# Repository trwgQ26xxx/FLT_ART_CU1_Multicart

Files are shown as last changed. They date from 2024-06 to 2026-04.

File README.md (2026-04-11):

# Multicart ROM module for Fiat Lancia Tester \ Alfa Romeo Tester \ Check Up 1

A multicart ROM module that replaces eight standard FLT modules. It contains eight ROM sets stored in a 512kB (4Mbit) flash memory, which can be switched on the fly.

Two variants are implemented: one using an Atmel AT89C2051 MCU (revisions A - green and B - blue), and another based on a Microchip ATtiny806 (revision C - yellow).

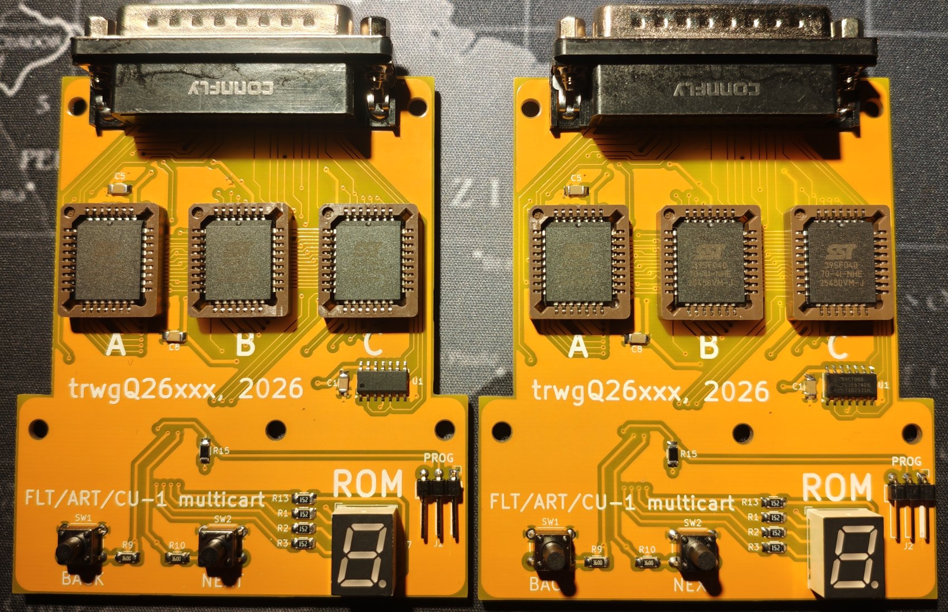
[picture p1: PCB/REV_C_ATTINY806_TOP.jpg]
REV_C_ATTINY806_TOP

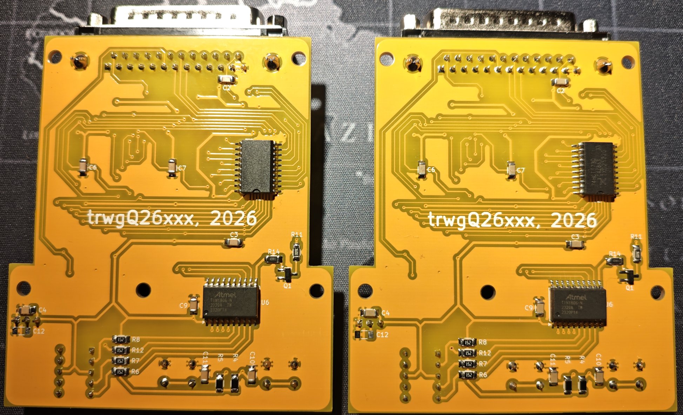
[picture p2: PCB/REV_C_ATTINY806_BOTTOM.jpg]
REV_C_ATTINY806_BOTTOM


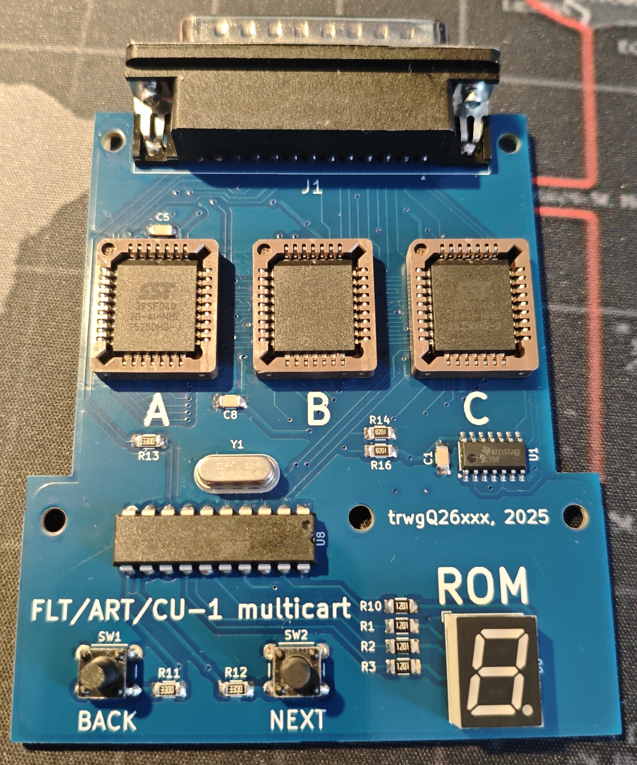
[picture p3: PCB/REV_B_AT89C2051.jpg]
REV_B_AT89C2051


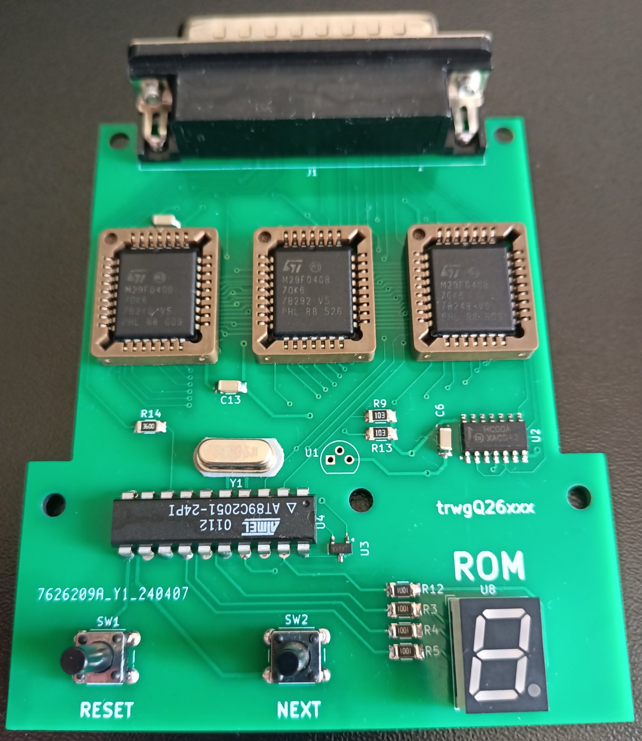
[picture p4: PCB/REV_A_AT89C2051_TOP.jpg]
REV_A_AT89C2051_TOP

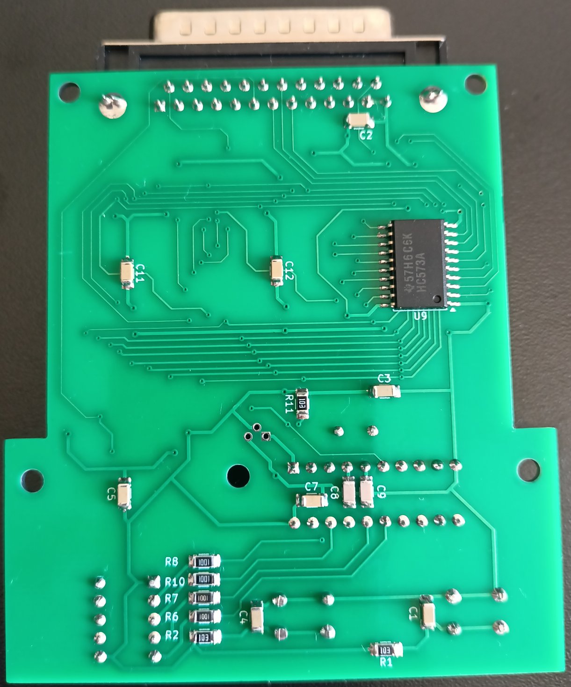
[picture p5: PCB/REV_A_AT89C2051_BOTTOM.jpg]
REV_A_AT89C2051_BOTTOM


# Disclaimer

I do not consent to the use of all or part of the project for commercial purposes!

Nie wyrażam zgody na wykorzystanie całości bądź części projektu w celach zarobkowych!

# License

Shield: [][cc-by-nc-sa]

This work is licensed under a
[Creative Commons Attribution-NonCommercial-ShareAlike 4.0 International License][cc-by-nc-sa].

[][cc-by-nc-sa]

[cc-by-nc-sa]: http://creativecommons.org/licenses/by-nc-sa/4.0/
[cc-by-nc-sa-image]: https://licensebuttons.net/l/by-nc-sa/4.0/88x31.png
[cc-by-nc-sa-shield]: https://img.shields.io/badge/License-CC%20BY--NC--SA%204.0-lightgrey.svg

# Directories organization

- **firmware** - MCU firmware written in C, provided for both the AT89C2051 and ATtiny806 variants.
- **merge** - A script that automatically combines up to eight modules into a single package suitable for loading onto the multicart.
- **PCB** - KiCad PCB project files, available for both the AT89C2051 and ATtiny806 hardware revisions.
- **DS** - Datasheets for all components used in the project.

# Instructions

Switching modules (ROMs) is accomplished by pressing the BACK and NEXT keys. With each press, a dot lights up on the display for the FLT reset time (approximately 200 ms). The display indicates the number of the currently running module.

The FLASH memories used, of 39SF040 type (or equivalent), have a capacity of 512kB. Considering that the largest FLT modules ROMs are 64kB, I designed the multicart's capacity to accomodate 8 modules.

# ROMS preparation

The FLASH memory contents can be changed according to the following principles.

**ROM index** | **Base offset**
:---: | :---:
1 | 0x00000
2 | 0x10000
3 | 0x20000
4 | 0x30000
5 | 0x40000
6 | 0x50000
7 | 0x60000
8 | 0x70000

Let's assume we want to load the module at index 3, for which the base offset is 0x20000.

**ROM** | **SIZE** | **The ROM given is PRESENT in the module being loaded at index 3** | **The ROM given is NOT PRESENT in the module being loaded at index 3**
:---: | :---: | :---: | :---:
A | 8kB | Load the content of ROM A into FLASH memory A addresses 0x20000-0x21FFF.Fill addresses 0x22000-0x2FFFF of FLASH memory A with 0xFF. | Fill addresses 0x20000-0x2FFFF of FLASH memory A with 0xFF.
B | 32kB | Load the content of ROM B into FLASH memory B addresses 0x28000-0x2FFFF. Fill addresses 0x20000-0x27FFF of FLASH memory B with 0xFF. | ROM B is always present.
B | 64kB | Load the content of ROM B into FLASH memory B addresses 0x20000-0x2FFFF. | ROM B is always present.
C | 32kB | Load the content of ROM C into FLASH memory C addresses 0x28000-0x2FFFF. Fill addresses 0x20000-0x27FFF of FLASH memory C with 0xFF. | Fill addresses 0x20000-0x2FFFF of FLASH memory C with 0xFF.
C | 64kB | Load the content of ROM C into FLASH memory C addresses 0x20000-0x2FFFF. | Fill addresses 0x20000-0x2FFFF of FLASH memory C with 0xFF.

It should be noted here that the utilization of FLASH memory A is at most 12.5%, as only 8kB of each 64kB bank is utilized. However, I opted for this solution to simplify the process of preparing Flash memory content, given the use of identical offsets.

# Notes

- Use the APX810-40SA as the reset supervisor for the AT89C2051 MCU (U7 on the PCB) in revisions A and B.

- Wiring the MPLAB ICD5 8P8C Connector to the Multicart PROG Connector (Revision C):

**SIGNAL** | **PROG pin** | **8P8C pin**
:---: | :---: | :---:
GND | 1 | 5
UPDI | 2 | 4
VCC | 3 | 6

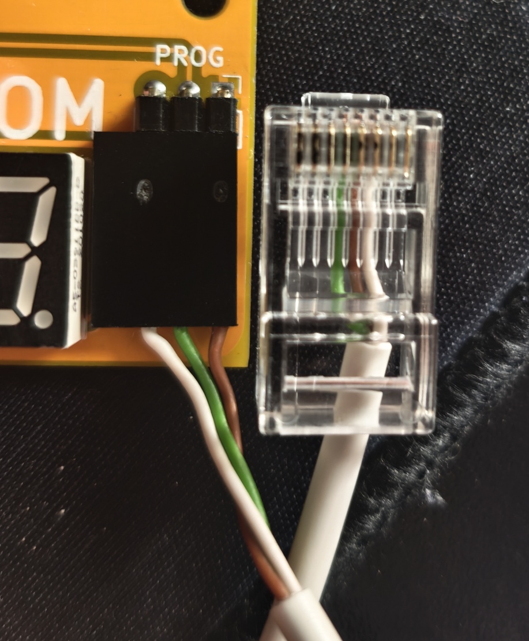
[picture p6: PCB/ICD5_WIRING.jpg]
ICD5_WIRING


- 0.28" LED displays are available in two pinout variants. The first variant uses common pins 1 and 6. The second variant uses common pins 3 and 8. **Revisions B and C of the project require the display with common pins 3 and 8.** The version with common pins 1 and 6 was used only in revision A.

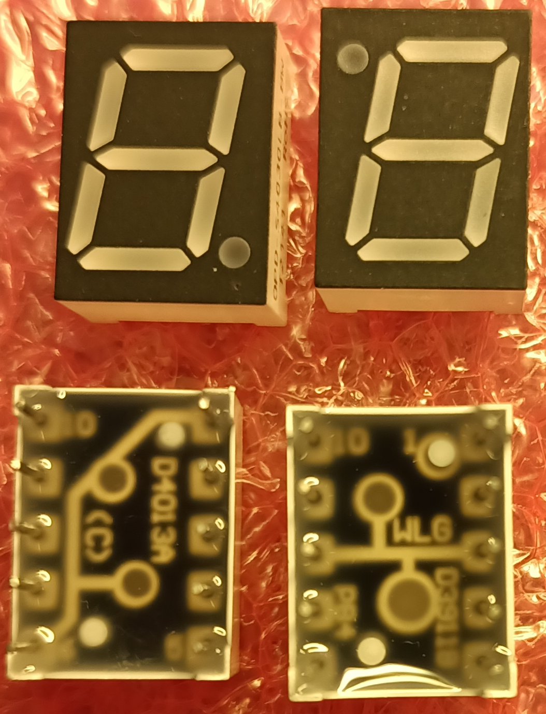
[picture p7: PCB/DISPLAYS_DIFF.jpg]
DISPLAYS_DIFF


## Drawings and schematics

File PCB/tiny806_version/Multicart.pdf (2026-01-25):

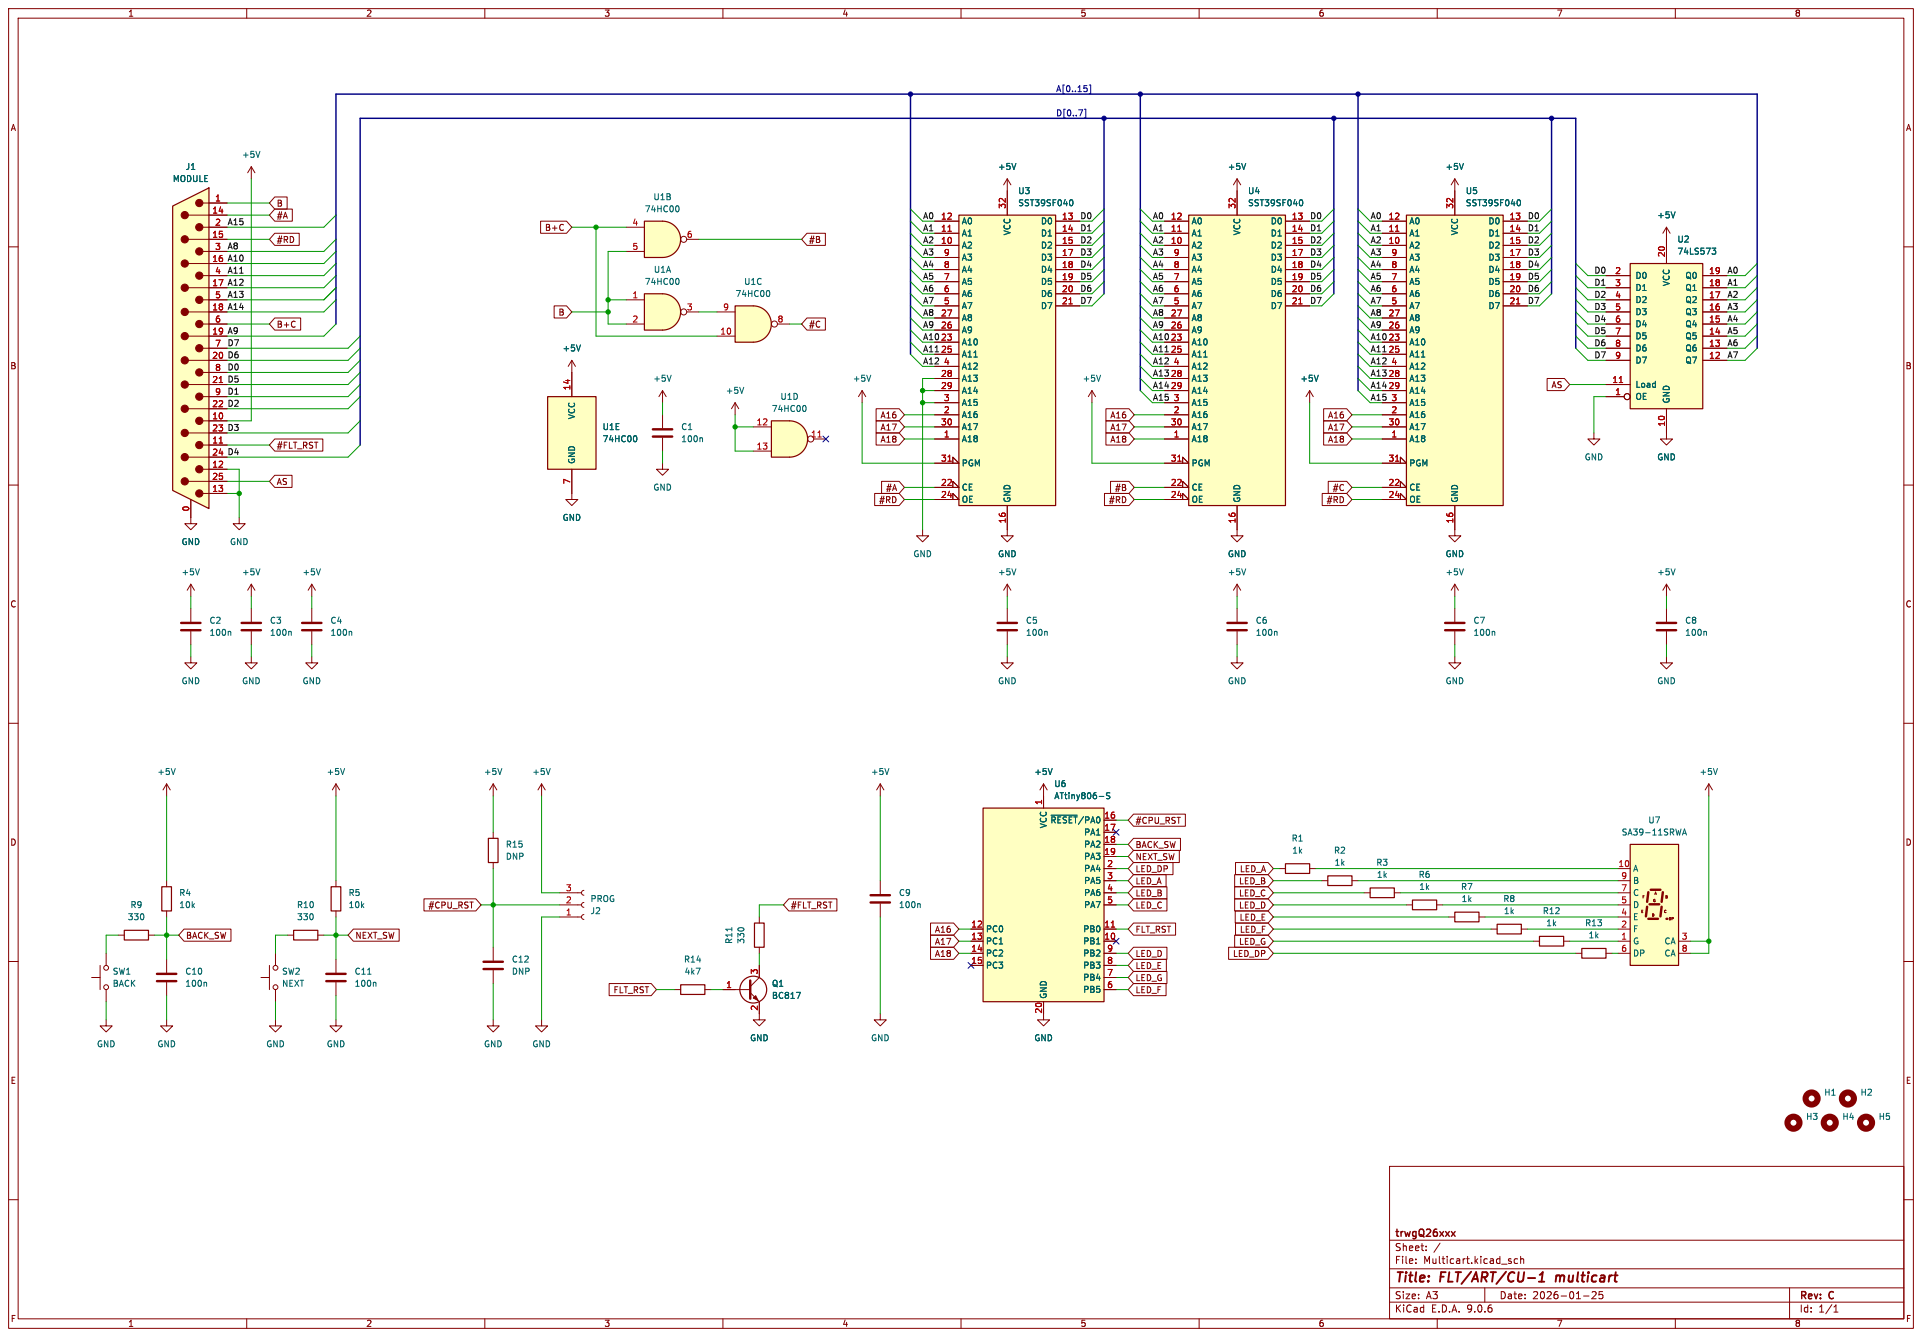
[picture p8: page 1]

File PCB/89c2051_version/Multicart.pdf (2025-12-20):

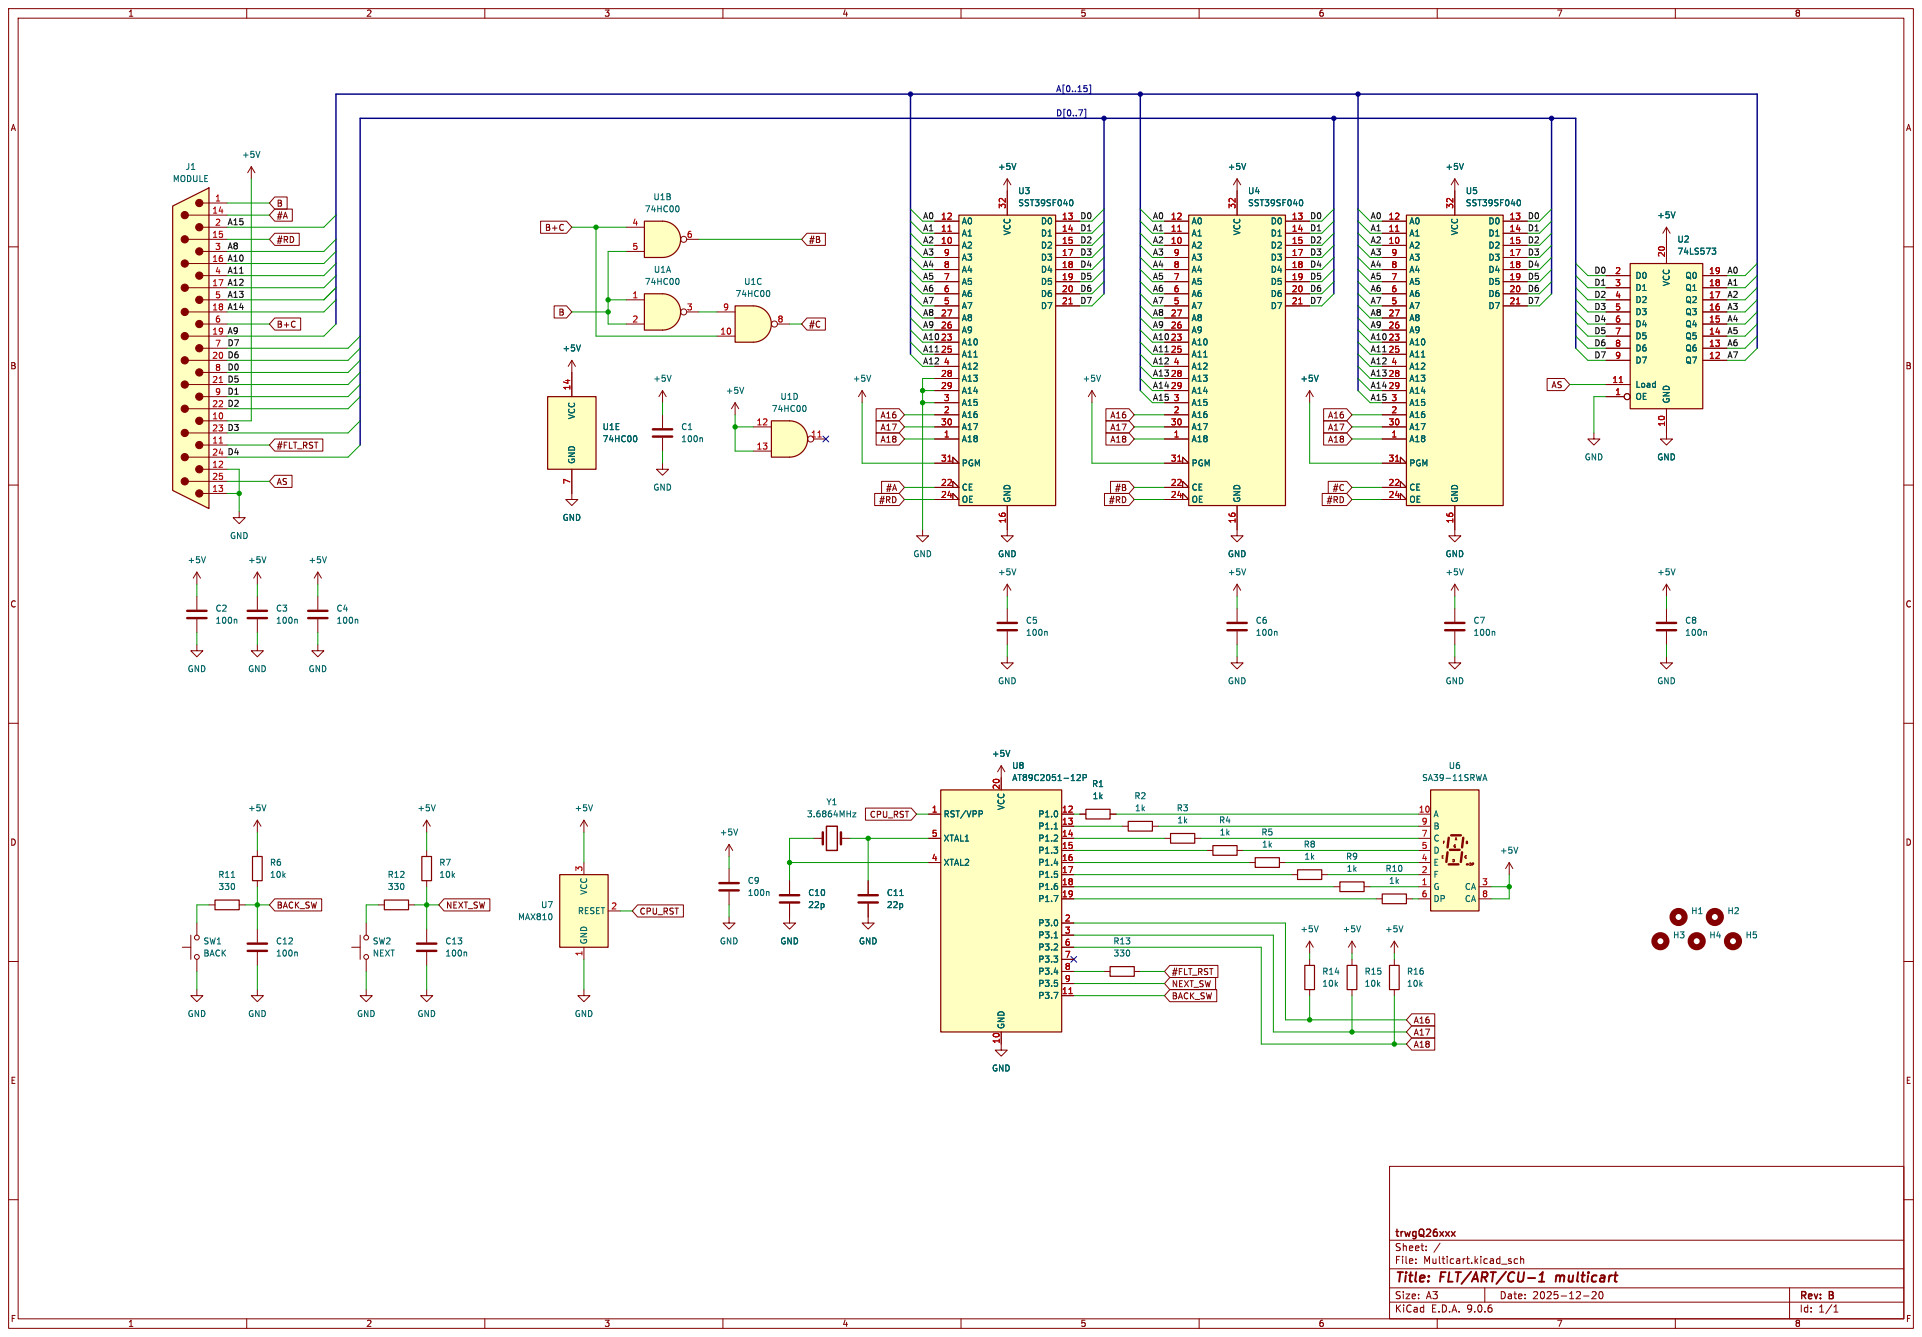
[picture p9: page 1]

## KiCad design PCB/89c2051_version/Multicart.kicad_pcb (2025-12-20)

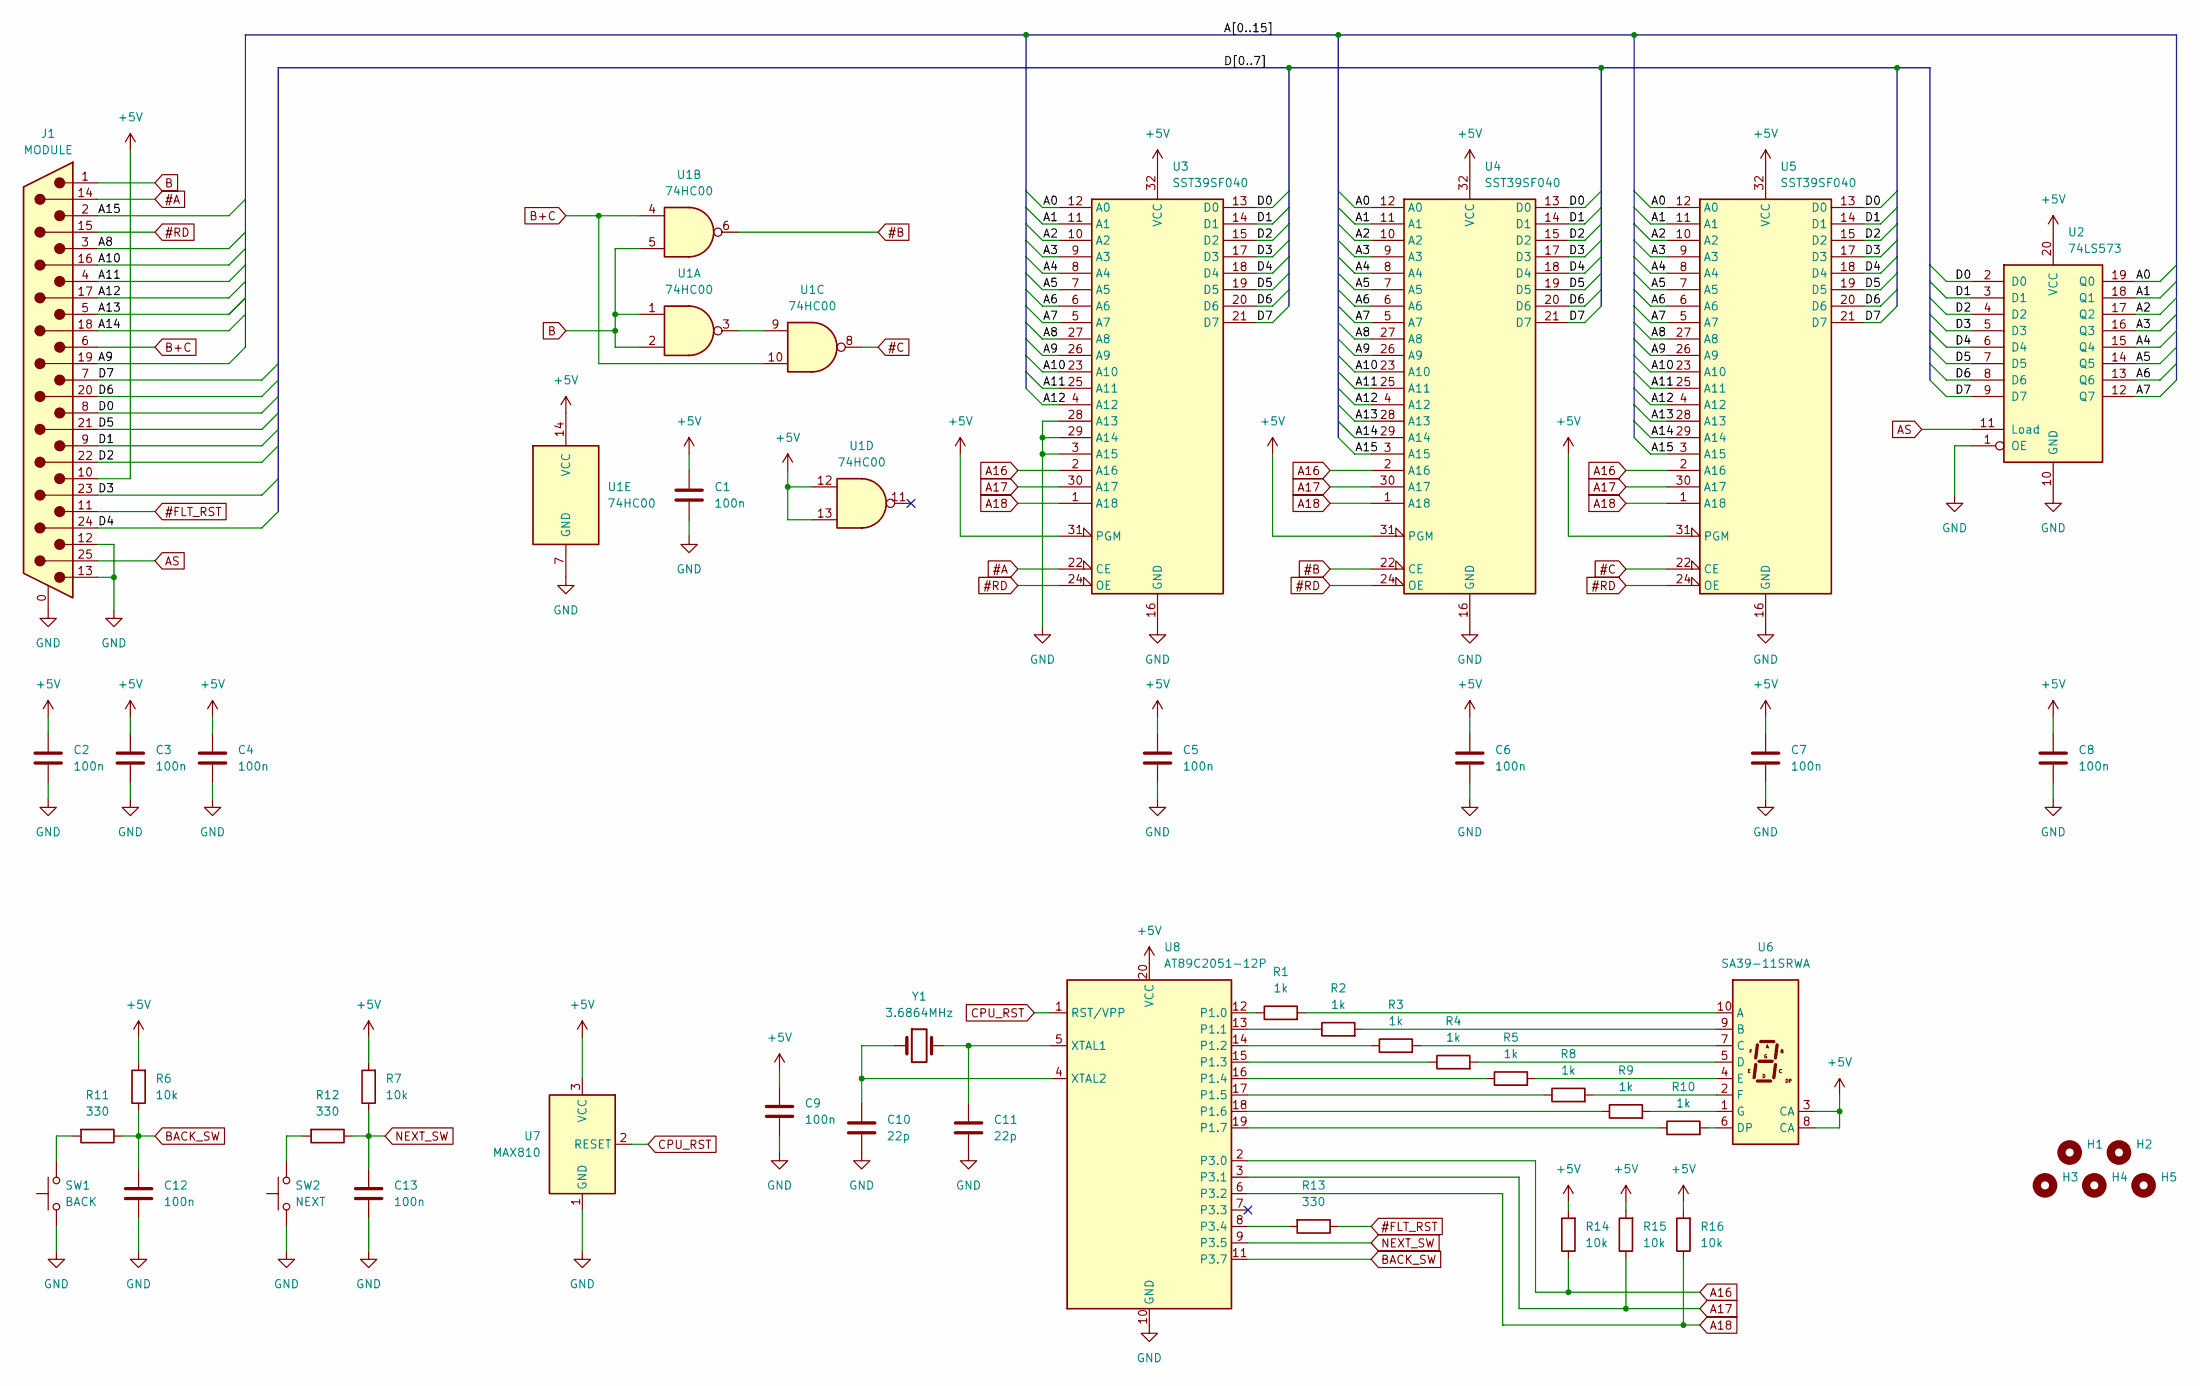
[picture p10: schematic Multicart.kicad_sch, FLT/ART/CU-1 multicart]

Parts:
C1, C2, C3, C4, C5, C6, C7, C8, C9, C12, C13: 100n; C_1206_3216Metric_Pad1.33x1.80mm_HandSolder
C10, C11: 22p; C_1206_3216Metric_Pad1.33x1.80mm_HandSolder
H1, H2, H3, H4, H5: MountingHole_3.2mm_M3_DIN965
J1: MODULE; DSUB-25_Male_Horizontal_P2.77x2.84mm_EdgePinOffset4.94mm_Ho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
R1, R2, R3, R4, R5, R8, R9, R10: 1k; R_1206_3216Metric_Pad1.30x1.75mm_HandSolder
R6, R7, R14, R15, R16: 10k; R_1206_3216Metric_Pad1.30x1.75mm_HandSolder
R11, R12, R13: 330; R_1206_3216Metric_Pad1.30x1.75mm_HandSolder
SW1: BACK; SW_PUSH_6mm
SW2: NEXT; SW_PUSH_6mm
U1: 74HC00; SOIC-14_3.9x8.7mm_P1.27mm
U2: 74LS573; SOIC-20W_7.5x12.8mm_P1.27mm
U3, U4, U5: SST39SF040; PLCC-32_11.4x14.0mm_P1.27mm
U6: SA39-11SRWA; Sx39-1xxxxx
U7: MAX810; SOT-23
U8: AT89C2051-12P; DIP-20_W7.62mm
Y1: 3.6864MHz; Crystal_HC49-4H_Vertical

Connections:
#A: J1.14, U3.22 (CE)
#B: U1.6, U4.22 (CE)
#C: U1.8, U5.22 (CE)
#FLT_RST: J1.11, R13.1
#RD: J1.15, U3.24 (OE), U4.24 (OE), U5.24 (OE)
+5V: C1.1, C2.1, C3.1, C4.1, C5.1, C6.1, C7.1, C8.1, C9.1, J1.10, R6.2, R7.2, R14.2, R15.2, R16.2, U1.12, U1.13, U1.14 (VCC), U2.20 (VCC), U3.31 (PGM), U3.32 (VCC), U4.31 (PGM), U4.32 (VCC), U5.31 (PGM), U5.32 (VCC), U6.3 (CA), U6.8 (CA), U7.3 (VCC), U8.20 (VCC)
/A0: U2.19 (Q0), U3.12 (A0), U4.12 (A0), U5.12 (A0)
/A1: U2.18 (Q1), U3.11 (A1), U4.11 (A1), U5.11 (A1)
/A2: U2.17 (Q2), U3.10 (A2), U4.10 (A2), U5.10 (A2)
/A3: U2.16 (Q3), U3.9 (A3), U4.9 (A3), U5.9 (A3)
/A4: U2.15 (Q4), U3.8 (A4), U4.8 (A4), U5.8 (A4)
/A5: U2.14 (Q5), U3.7 (A5), U4.7 (A5), U5.7 (A5)
/A6: U2.13 (Q6), U3.6 (A6), U4.6 (A6), U5.6 (A6)
/A7: U2.12 (Q7), U3.5 (A7), U4.5 (A7), U5.5 (A7)
/A8: J1.3, U3.27 (A8), U4.27 (A8), U5.27 (A8)
/A9: J1.19, U3.26 (A9), U4.26 (A9), U5.26 (A9)
/A10: J1.16, U3.23 (A10), U4.23 (A10), U5.23 (A10)
/A11: J1.4, U3.25 (A11), U4.25 (A11), U5.25 (A11)
/A12: J1.17, U3.4 (A12), U4.4 (A12), U5.4 (A12)
/A13: J1.5, U4.28 (A13), U5.28 (A13)
/A14: J1.18, U4.29 (A14), U5.29 (A14)
/A15: J1.2, U4.3 (A15), U5.3 (A15)
/D0: J1.8, U2.2 (D0), U3.13 (D0), U4.13 (D0), U5.13 (D0)
/D1: J1.9, U2.3 (D1), U3.14 (D1), U4.14 (D1), U5.14 (D1)
/D2: J1.22, U2.4 (D2), U3.15 (D2), U4.15 (D2), U5.15 (D2)
/D3: J1.23, U2.5 (D3), U3.17 (D3), U4.17 (D3), U5.17 (D3)
/D4: J1.24, U2.6 (D4), U3.18 (D4), U4.18 (D4), U5.18 (D4)
/D5: J1.21, U2.7 (D5), U3.19 (D5), U4.19 (D5), U5.19 (D5)
/D6: J1.20, U2.8 (D6), U3.20 (D6), U4.20 (D6), U5.20 (D6)
/D7: J1.7, U2.9 (D7), U3.21 (D7), U4.21 (D7), U5.21 (D7)
A16: R14.1, U3.2 (A16), U4.2 (A16), U5.2 (A16), U8.2 (P3.0)
A17: R15.1, U3.30 (A17), U4.30 (A17), U5.30 (A17), U8.3 (P3.1)
A18: R16.1, U3.1 (A18), U4.1 (A18), U5.1 (A18), U8.6 (P3.2)
AS: J1.25, U2.11 (Load)
B: J1.1, U1.1, U1.2, U1.5
B+C: J1.6, U1.4, U1.10
BACK_SW: C12.1, R6.1, R11.1, U8.11 (P3.7)
CPU_RST: U7.2 (RESET), U8.1 (RST/VPP)
GND: C1.2, C2.2, C3.2, C4.2, C5.2, C6.2, C7.2, C8.2, C9.2, C10.2, C11.2, C12.2, C13.2, J1.0, J1.12, J1.13, SW1.1, SW2.1, U1.7 (GND), U2.1 (OE), U2.10 (GND), U3.3 (A15), U3.16 (GND), U3.28 (A13), U3.29 (A14), U4.16 (GND), U5.16 (GND), U7.1 (GND), U8.10 (GND)
NEXT_SW: C13.1, R7.1, R12.1, U8.9 (P3.5)
unnamed: R11.2, SW1.2
unnamed: R12.2, SW2.2
unnamed: U1.3, U1.9
unnamed: R1.2, U6.10 (A)
unnamed: R2.2, U6.9 (B)
unnamed: R3.2, U6.7 (C)
unnamed: R4.2, U6.5 (D)
unnamed: R10.2, U6.6 (DP)
unnamed: R5.2, U6.4 (E)
unnamed: R8.2, U6.2 (F)
unnamed: R9.2, U6.1 (G)
unnamed: R1.1, U8.12 (P1.0)
unnamed: R2.1, U8.13 (P1.1)
unnamed: R3.1, U8.14 (P1.2)
unnamed: R4.1, U8.15 (P1.3)
unnamed: R5.1, U8.16 (P1.4)
unnamed: R8.1, U8.17 (P1.5)
unnamed: R9.1, U8.18 (P1.6)
unnamed: R10.1, U8.19 (P1.7)
unnamed: R13.2, U8.8 (P3.4)
unnamed: C11.1, U8.5 (XTAL1), Y1.2
unnamed: C10.1, U8.4 (XTAL2), Y1.1

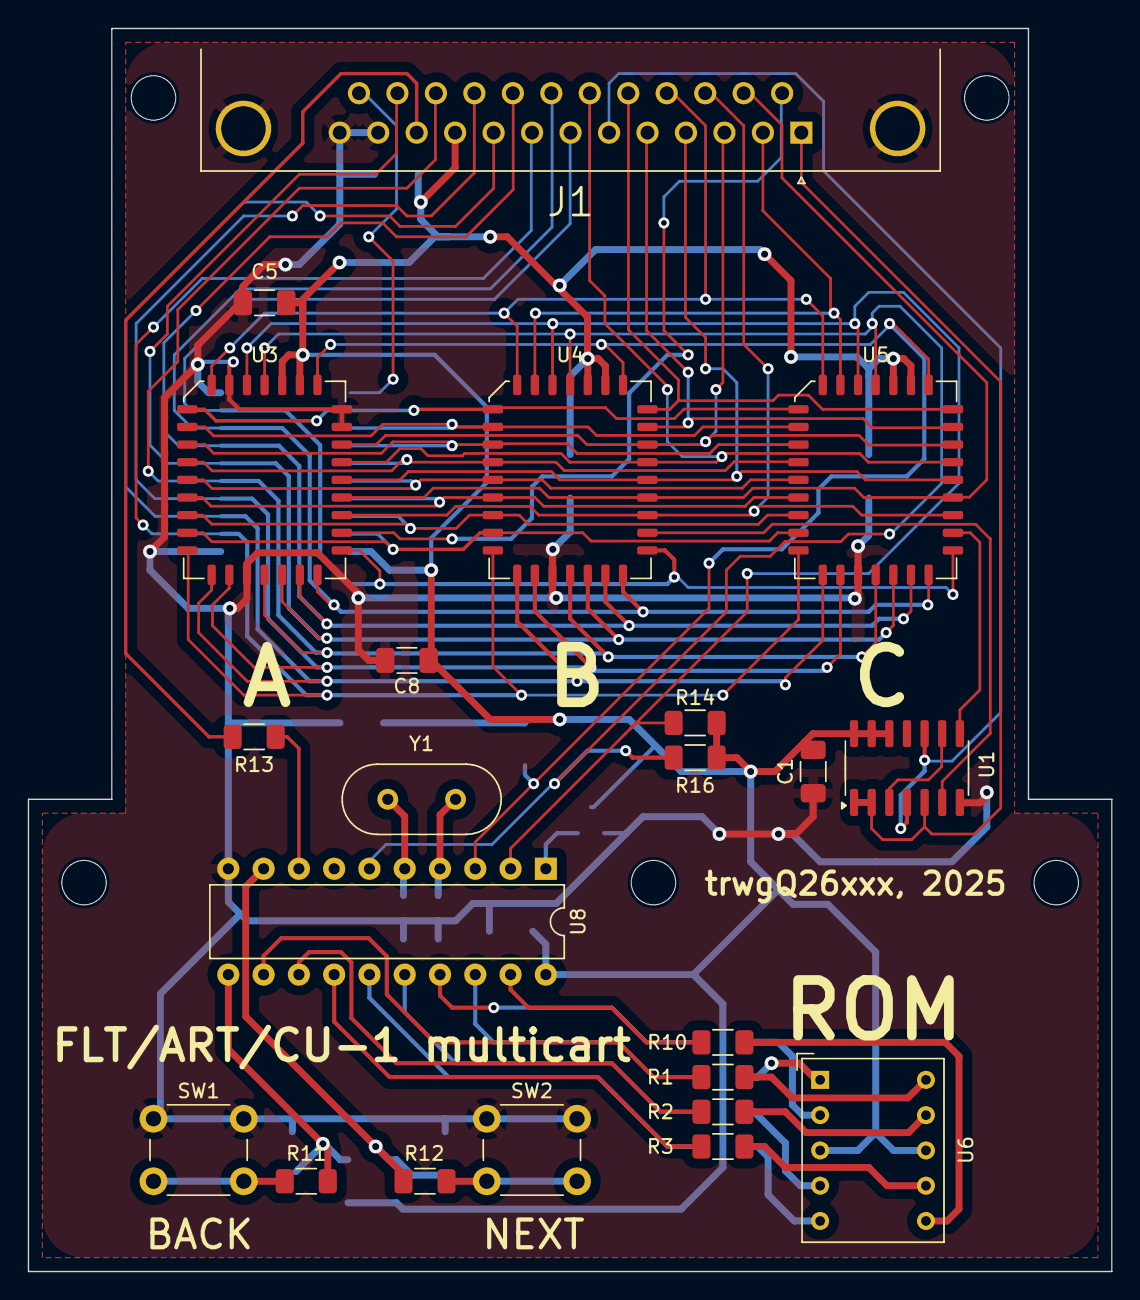
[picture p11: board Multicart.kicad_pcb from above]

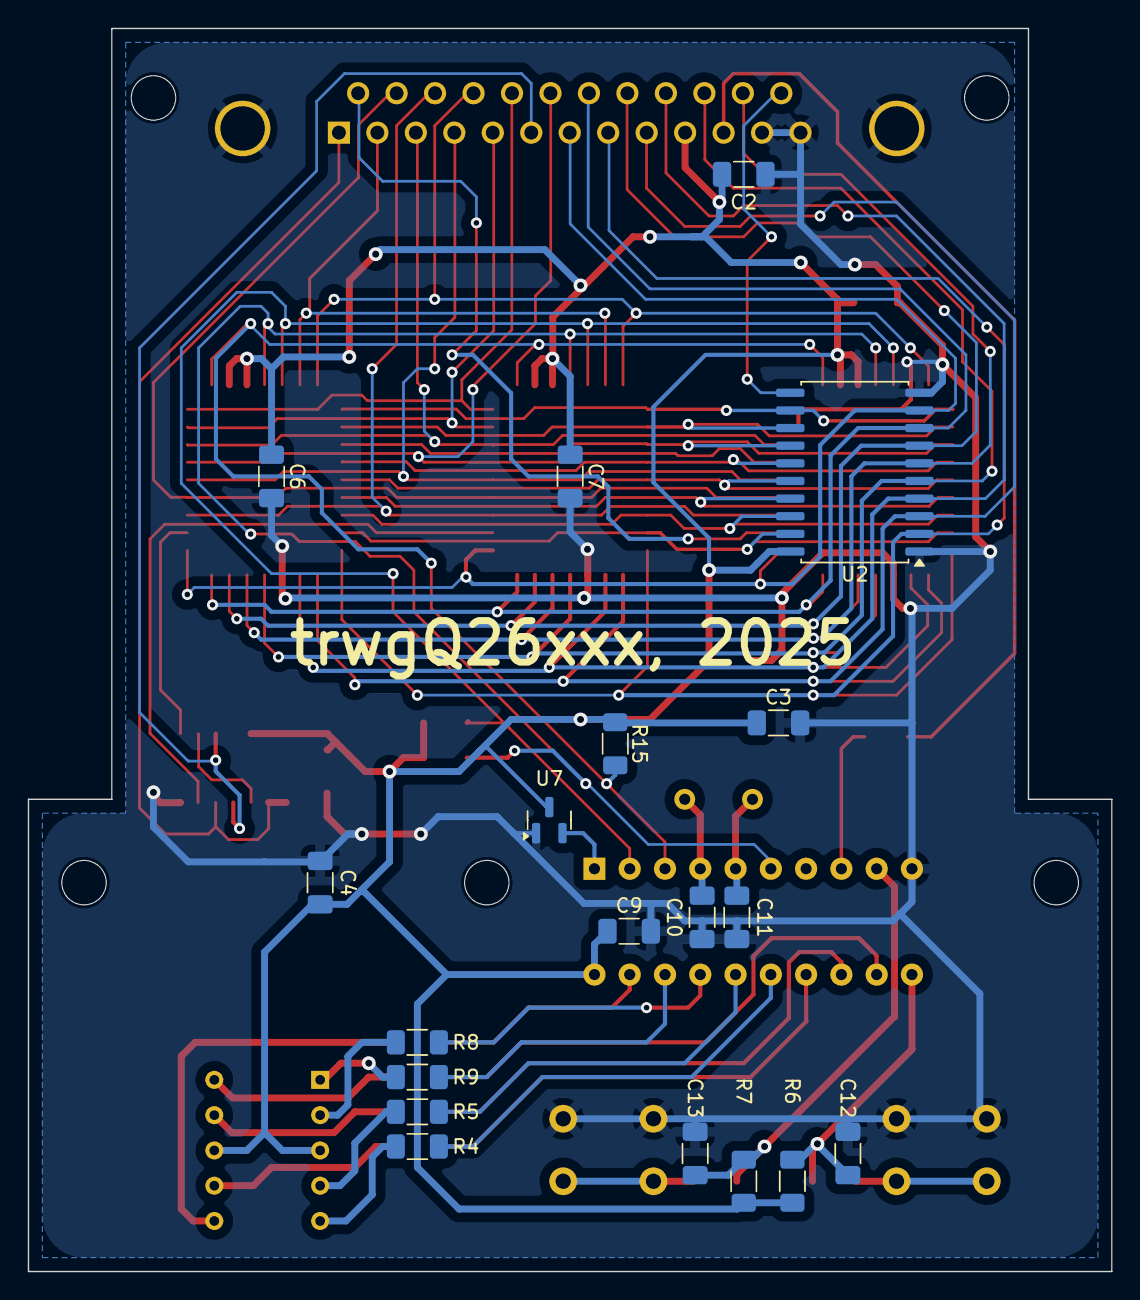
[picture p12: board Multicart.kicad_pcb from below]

Board: 2 copper layers, 78.0 x 89.5 mm, 46 parts (19 on the bottom side), 62 nets.

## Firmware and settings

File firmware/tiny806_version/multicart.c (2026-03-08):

/*
Project name:	FLT/CU1 multicart
Author: 		trwgQ26xxx
Date:			25.02.2026
Target MCUs:	Attiny 406/806
Compiler:		AVR_8_bit_GNU_Toolchain_4.0.0_52), Microchip.ATtiny_DFP.3.3.272
*/

#include <stdint.h>
#include <stdbool.h>

#include <avr/io.h>
#include <avr/interrupt.h>
#include <avr/wdt.h>
#include <avr/fuse.h>

/*
------------------ CONNECTIONS ------------------

7 segment display:
PA5 - PA7 => A, B, C; PB2 - PB5 => D, E, G, F; PA4 = DP

Flash memory address lines:
PC0 - PC2 => A16 - A18; PC3 = NC (A19 - FFU)

FLT reset:
PB0 = #FLT_RST

Push buttons:
PA3 = NEXT_SW, PA2 = BACK_SW

------------------ CONNECTIONS ------------------
*/

#define NUMBER_OF_BANKS	8

#define F_TIMER			(F_CPU / 256)					/* Hz, for TCA0 with DIV256 prescaler */
#define KEYB_DELAY		200								/* ms */
#define TIMER_VAL		((KEYB_DELAY * F_TIMER) / 1000)	/* ticks */
#define TIMER_VAL_MAX	0xFFFF							/* Max value for 16-bit timer */

#if (TIMER_VAL > TIMER_VAL_MAX)
	#error "Set keyboard delay is larger than maximum possible"
#endif

#define NEXT_KEY_IS_PRESSED				(!(PORTA.IN & (1 << 3)))
#define BACK_KEY_IS_PRESSED				(!(PORTA.IN & (1 << 2)))
#define ALL_KEYS_ARE_RELEASED			((PORTA.IN & (1 << 3)) && (PORTA.IN & (1 << 2)))

/* DIGITS: 1 - 8 */
volatile const unsigned char led_codes[NUMBER_OF_BANKS] = {0x06, 0x3B, 0x2F, 0x66, 0x6D, 0x7D, 0x07, 0x7F};

volatile bool keyboard_locked = false;
volatile uint8_t current_mem_bank = 0;

static void Run_FLT(bool run);
static void Change_mem_bank(uint8_t bank);
static void Update_LED_Display(uint8_t digit, bool dot_status);

static void Start_Timer(void);
static void Switch_Bank(void);

int main(void)
{
	/* Poke WDT */
	wdt_reset();

	/* FUSE set to 16MHz, enable 16 prescaler so F_CPU is 1MHz */
	_PROTECTED_WRITE(CLKCTRL.MCLKCTRLB, CLKCTRL_PDIV_16X_gc | CLKCTRL_PEN_bm);

	/* Initialize timer */
	TCA0.SINGLE.CTRLA = TCA_SINGLE_CLKSEL_DIV256_gc;	/* Set prescaler to 256 */
	TCA0.SINGLE.CTRLB = TCA_SINGLE_WGMODE_NORMAL_gc;	/* Set normal mode */
	TCA0.SINGLE.CTRLC = 0;								/* No compare channels */
	TCA0.SINGLE.CTRLD = 0;								/* No split mode */
	TCA0.SINGLE.CTRLECLR = TCA_SINGLE_DIR_bm;			/* Clear direction bit (count up mode) */
	TCA0.SINGLE.EVCTRL = 0;								/* No event control */
	TCA0.SINGLE.PER = TIMER_VAL;						/* Set period for desired delay */
	TCA0.SINGLE.CNT = 0;								/* Clear counter */

	TCA0.SINGLE.INTFLAGS = TCA_SINGLE_OVF_bm;			/* Clear interrupt flag */
	TCA0.SINGLE.INTCTRL = TCA_SINGLE_OVF_bm;			/* Enable overflow interrupt */

	/* Initialize memory bank switch output */
	PORTC.DIRSET = 0x0F;
	PORTC.OUTCLR = 0x0F;								/* Set to first bank */

	/* Initialize FLT reset output */
	PORTB.DIRSET = (1 << 0);
	PORTB.OUTSET = (1 << 0);							/* Hold in reset */

	/* Initialize display */
	PORTA.DIRSET = 0xF0; PORTB.DIRSET = 0x3C;
	PORTA.OUTSET = 0xF0; PORTB.OUTSET = 0x3C;			/* LED display off */

	/* Initialize keyboard inputs */
	PORTA.DIRCLR = (1 << 3) | (1 << 2);
	PORTA.PIN2CTRL = PORT_PULLUPEN_bm;					/* Enable pull-up on PA2 (BACK_SW) */
	PORTA.PIN3CTRL = PORT_PULLUPEN_bm;					/* Enable pull-up on PA3 (NEXT_SW) */

	/* Configure unused pins */
	PORTA.DIRCLR = (1 << 1) | (1 << 0);					/* Configure PA0 and PA1 as inputs */
	PORTA.PIN0CTRL = PORT_PULLUPEN_bm;					/* Enable pull-up on PA0 */
	PORTA.PIN1CTRL = PORT_PULLUPEN_bm;					/* Enable pull-up on PA1 */
	PORTB.DIRCLR = (1 << 1);							/* Configure PB1 as input */
	PORTB.PIN1CTRL = PORT_PULLUPEN_bm;					/* Enable pull-up on PB1 */

	/* Init variables */
	current_mem_bank = 0;
	keyboard_locked = true;

	/* Enable interrupts globally */
	sei();

	/* Do one transaction on start */
	Switch_Bank();

	while(true)
	{
		/* If keyboard is unlocked */
		if(keyboard_locked == false)
		{
			/* Check NEXT key */
			if(NEXT_KEY_IS_PRESSED)
			{
				/* If pressed, advance bank forward */
				if(current_mem_bank >= (NUMBER_OF_BANKS - 1))
				{
					current_mem_bank = 0;
				}
				else
				{
					current_mem_bank++;
				}

				Switch_Bank();
			}
			/* Check BACK key */
			else if(BACK_KEY_IS_PRESSED)
			{
				/* If pressed, advance bank backward */
				if(current_mem_bank == 0)
				{
					current_mem_bank = NUMBER_OF_BANKS - 1;
				}
				else
				{
					current_mem_bank--;
				}

				Switch_Bank();
			}
		}

		/* Poke WDT */
		wdt_reset();
	}
}

ISR(TCA0_OVF_vect)
{
	/* Kill timer */
	TCA0.SINGLE.CTRLA &= ~TCA_SINGLE_ENABLE_bm;

	/* Clear IRQ flag */
	TCA0.SINGLE.INTFLAGS = TCA_SINGLE_OVF_bm;

	/* Run FLT */
	Run_FLT(true);

	/* Update display, hide dot */
	Update_LED_Display(current_mem_bank, false);

	/* Check if all keys are released */
	if(ALL_KEYS_ARE_RELEASED)
	{
		/* Unlock keyboard */
		keyboard_locked = false;
	}
	else
	{
		/* Waiting for buttons to be released, restart timer */
		Start_Timer();
	}
}

static void Start_Timer(void)
{
	/* Kill timer */
	TCA0.SINGLE.CTRLA &= ~TCA_SINGLE_ENABLE_bm;

	/* Clear timer */
	TCA0.SINGLE.CNT = 0;

	/* Clear IRQ flag */
	TCA0.SINGLE.INTFLAGS = TCA_SINGLE_OVF_bm;

	/* Start timer */
	TCA0.SINGLE.CTRLA |= TCA_SINGLE_ENABLE_bm;
}

static void Switch_Bank(void)
{
	/* Lock keyboard */
	keyboard_locked = true;

	/* Halt FLT */
	Run_FLT(false);

	/* Switch bank */
	Change_mem_bank(current_mem_bank);

	/* Update display, show dot */
	Update_LED_Display(current_mem_bank, true);

	/* Start timer */
	Start_Timer();
}

static void Run_FLT(bool run)
{
	/* Set FLT control pin */
	if(run == true)
		PORTB.OUTSET = (1 << 0);
	else
		PORTB.OUTCLR = (1 << 0);
}

static void Change_mem_bank(uint8_t bank)
{
	/* Change memory bank */
	PORTC.OUTCLR = 0x0F;
	PORTC.OUTSET = (bank & 0x0F);
}

static void Update_LED_Display(uint8_t digit, bool dot_status)
{
	/* Check if digit is within range */
	if(digit >= NUMBER_OF_BANKS)
		digit = 0;

	/* Clear display */
	PORTA.OUTSET = 0xE0;
	PORTB.OUTSET = 0x3C;

	/* Update digit */
	PORTA.OUTCLR = (led_codes[digit] & 0x07) << 5;
	PORTB.OUTCLR = (led_codes[digit] & 0x78) >> 1; // ((led_codes[digit] & 0x78) >> 3) << 2

	/* Update dot */
	if(dot_status == true)
		PORTA.OUTCLR = (1 << 4);
	else
		PORTA.OUTSET = (1 << 4);
}

/* FUSE configuration */
FUSES = {
	.WDTCFG  = 0x06,	/* Watchdog: Timeout = 256CLK (0.256s), Window mode off */
	.BODCFG  = 0xF5,	/* BOD: Level = 4.2V, Sample Frequency = 125Hz, Enabled mode in active & sleep */
	.OSCCFG  = 0x01,	/* Internal 16MHz RC Oscillator, calibration registers unlocked */
	.SYSCFG0 = 0xF2,	/* No CRC, Reset/UPDI pin configured as GPIO, EEPROM erased during chip erase */
	.SYSCFG1 = 0x04,	/* Start-Up Time = 8ms */
	.APPEND  = 0x00,	/* Application Code Section End, unused */
	.BOOTEND = 0x00		/* Boot Section End, unused */
};

/* LOCKBIT configuration */
LOCKBITS = 0xC5;		/* Memory access is unlocked */

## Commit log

2024-04-20 PCB project added
    [Multicart.kicad_pcb, Multicart.kicad_sch]
2024-04-20 Schematic in PDF added
2024-04-23 LED display fix
2024-04-26 Cosmetic change: compilation error is shown when set delay exceeds maximum
    [multicart.c]
2025-12-20 PCB updated, B will be the last revision to use 89C2051
    [Multicart.kicad_pcb, Multicart.kicad_sch]
2025-12-20 Update for production
    [Multicart.kicad_pcb, Multicart.kicad_sch]
2026-01-25 MCU changed to Attiny 406/806, PCB updated to revision C
    [Multicart.kicad_pcb, Multicart.kicad_sch]
2026-02-08 Last PCB update before production
    [Multicart.kicad_pcb]
2026-02-08 Added 8k ROM case to merge script
2026-03-08 PCB directory splitted for two (89C2051 and ATtiny806) versions
    [Multicart.kicad_pcb, Multicart.kicad_sch]
